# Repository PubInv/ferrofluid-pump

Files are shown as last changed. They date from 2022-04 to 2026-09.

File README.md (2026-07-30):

# Ferrofluid Pump
## July 7th

Using Rob's pump with three electromagnets and one permanent magnet at priming, with a 10 amp power supply,
with a period of 300 ms and {0.0,0.4} interval timing, we measured 8 grams per minute, the best that we have yet.

## Previously

Ferrofluid pump with rotating water blobs and no moving parts

A video of best results:

[https://youtu.be/B2Wuy3dDc4E?si=2YtM-PyZvu_GHdCr](https://youtu.be/B2Wuy3dDc4E?si=2YtM-PyZvu_GHdCr)

# The Latest Version

Our latest multi-magnet version (which has not yet been tested) is here:





# The Boat-Pump Idea

This idea seems to work:

<a href="https://youtube.com/shorts/PQ8AnhncvDY?feature=share" title="Boat Pump Example">
  magnet switched on and off asking as pump
</a>

[https://youtube.com/shorts/PQ8AnhncvDY?feature=share](https://youtube.com/shorts/PQ8AnhncvDY?feature=share)

As a prelude to the 7-circle pump described in the technical paper you can find in the "doc" directory here,
we are attempting to make a very, very simple, pump.
The images below represent our simple "pump" idea. 
We just raise a small bolus of fluid, and then drop it onto a ramp.
This performance of this pump is being worked out, but of course 
it is weak.
The "head" is just a few millimeters, and the flow has not yet been measured.
However, we think it is still important in that it is indeed a
pump with no moving parts.



We use a hot-melt glue to try to seal the "chamber" so that the fluid will flow down the ramp:



# Possible Reading

[https://www.researchgate.net/publication/245883107_Design_fabrication_and_testing_of_fixed-valve_micro-pumps](https://www.researchgate.net/publication/245883107_Design_fabrication_and_testing_of_fixed-valve_micro-pumps)

A closely related paper is:
article{ando2009ferrofluidic,
  title={Ferrofluidic pumps: a valuable implementation without moving parts},
  author={Ando, Bruno and Ascia, Alberto and Baglio, Salvatore and Pitrone, Nicola},
  journal={IEEE Transactions on Instrumentation and Measurement},
  volume={58},
  number={9},
  pages={3232--3237},
  year={2009},
  publisher={IEEE}
}

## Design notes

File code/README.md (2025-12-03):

# microPython on ESP32

* Install UART driver [1]
* Install Thonny IDE [2], [3]
* Download microPython firmware [4]
* Clone esptool [5]
* Install micropython to the ESP32
  * Either directly using esptool
  * Or using Thonny Tools -> Options -> Interpreter -> Install microPython
* Select the ESP32 as the runtime to use and auto-select port

[1] - https://www.silabs.com/developers/usb-to-uart-bridge-vcp-drivers?tab=downloads

[2] - https://randomnerdtutorials.com/getting-started-thonny-micropython-python-ide-esp32-esp8266/

[3] - https://thonny.org/

[4] - https://micropython.org/resources/firmware/ESP32_GENERIC-20240222-v1.22.2.bin

[5] - https://github.com/espressif/esptool

# Run pump.py on the ESP32

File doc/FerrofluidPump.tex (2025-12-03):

\documentclass[12pt]{article}
%Uncomment next line if AMS fonts required
%\usepackage{iopams}
\usepackage{graphicx}
\usepackage{hyperref}   % to set up hyperlinks
\hypersetup{
	colorlinks=true,
	linkcolor=blue,
	citecolor=blue,
	urlcolor=blue,
}

\begin{document}

%%\note{A novel passive
%%ferrofluid check (one-way) valve}

\title{Pumping Ferrofluid With Only Liquid}

\maketitle

%%% first author
\author{Robert L. Read}

\begin{abstract}

  Currently this is very preliminary. This is an attempt to design a pump that can efficiently pump ferrofluid with no moving parts
  except the ferrofluid and two blobs of an immiscible, incompressible fluid, such as water.
  Eliminating moving parts allows miniaturization and potentially fabrication as a chip.
  A miniature pump could be used for cooling a chip and for ``lab on a chip'' applications.
  The proposed design uses two permanent magnets and seven controllable electromagnets.
  The design was developed from considering the minimal topological connection of fixed chambers.
  It has four distinct phases, each phase having a distinct magnetic configuration.
\end{abstract}

%
% Uncomment for keywords
\vspace{2pc}
\noindent{\it Keywords}: ferrofluid pump

% Uncomment if a separate title page is required
%\maketitle
%
% For two-column output uncomment the next line and choose [10pt] rather than [12pt] in the \documentclass declaration
%\ioptwocol
%

%%%%%%%%%%%%%%%%%%%%%%%%%%%%%%%%%%%%%%%%%%%%%%%%%%%%%%%%%%%%%%%%%%%%%%
\section{Introduction}

Ferrofluid can be manipulated by electronically controlled magnetic
fields to exert force on fluids\cite{torres2014recent,kole2021engineering,ozbey2015modeling}.
This makes it possible to build pneumatic or hydraulic
devices, perhaps on very small scales,
such as a single chip\cite{yamahata2003ferrofluid,hatch2001ferrofluidic}, to
miniaturize fluid handling.
This has been proposed for biomedical purposes\cite{michelson2019novel}
that would use water or body fluids,
although this paper reports only on experiments done with air.
Miniature pumps and valves could be used to make a “lab on a chip” (LOC) or
even to heat or cool different chip areas.

%%%%%%%%%%%%%%%%%%%%%%%%%%%%%%%%%%%%%%%%%%%%%%%%%%%%%%%%%%%%%%%%%%%%%%
\section{Related Research}

A number of papers report on ferrofluid pumps, focusing in particular
on micropump and lab-on-a-chip applications\cite{ozbey2015modeling,hsu2018biocompatible}.
Many of these papers use
a version of mechanical valve not based on passive
ferrofluid, even though they move a ferrofluid bolus
with a magnetic field.
For example,
a corrugated silicone micro valve\cite{yamahata2003ferrofluid,yamahata2005plastic}
has been reported.
Other researchers use active valves, which require synchronization with
the ferrofluid plug to form a pump,
such as \cite{menz2000fluidic}, which
describes an active {\em T-Valve} with a moving ferrofluid plug, and
\cite{ando2009ferrofluidic} describes a complete fluid pump with valves
that use
active control of a ferrofluid bolus.
At least two additional kinds of active valves, a {\em well valve} and
{\em Y-valve}, have
been described\cite{hartshorne2004ferrofluid}.
Active control is possible because the
action of the plunger or bolus may be synchronized with the opening and closing
of the valves.
Nonetheless a passive valve would be simpler and less
expensive, and would not require knowledge of the timing of the
plunger.

An interesting functional micropump in which the
moving ferrofluid bolus merges with a fixed ferrofluid valve and then
separates on each pumping cycle has been described\cite{hatch2001ferrofluidic}.

An interesting devices induces a flow directly in ferrofluid
with no moving parts,
presumable based on the rotation of clumps of ferrofluid
\cite{mao2011direct}.

A good motivation of the need to make a ferrofluid pump and a functioning pump
is presented by \cite{YAO2024115537}. The goal of this work is to something similar
to Yao with no moving parts.

\section{The Idea}

There is no known way to directly move a mass of ferrfluid which is immersed in
ferrofluid.
The idea of moving a ferrofluid plug or bolus which is bouneded by air or water
via electromagnets turned on or off is well known. A slight inversion of this
idea is to use two boluses to trap a blob of water. The water thus remains
a separator. In the diagrams below it is represented as a ``W'',
and the ferrofluid as an ``F''.
The separator allows us to move the bolus slightly.
In order to create a pump, we need to recycle this separator, rather than
moving it once, as in a piston.

If we combine this with the idea of a moving bolus ``picking up'' some ferrofluid
and then dropping some of that ferrofluid, we can have a two circulating water blobs
and two circulating ferrofluid plugs. One ferrofluid plug, which is moving from the
inlet to the outlet, is larger.
The other plug is smaller, and merely separating the water plugs as it is returned.

If we reduce this to a minimal configuration, we have a circle of seven regions
of equal size. The inlet and the outlet prevent the water blobs from escaping by
having permanent magnets in place. The water blobs can never displace these
locks, represented by ``L'' in our diaggram. The inlet of the pump has an
inexhaustible supply of ferrofluid represented as a source (``S''). The
outlet is represented as a drain ``D''.

The water plugs must always be kept separated by ferrofluid plugs. However,
these plugs can pull fluid from the source and push it into the drain if
so driven by the changing magnets in the seven dynamic regions.
By cycling through four configurations as depicted, we can move ferrofluid
from the source to the drain.

\begin{figure}
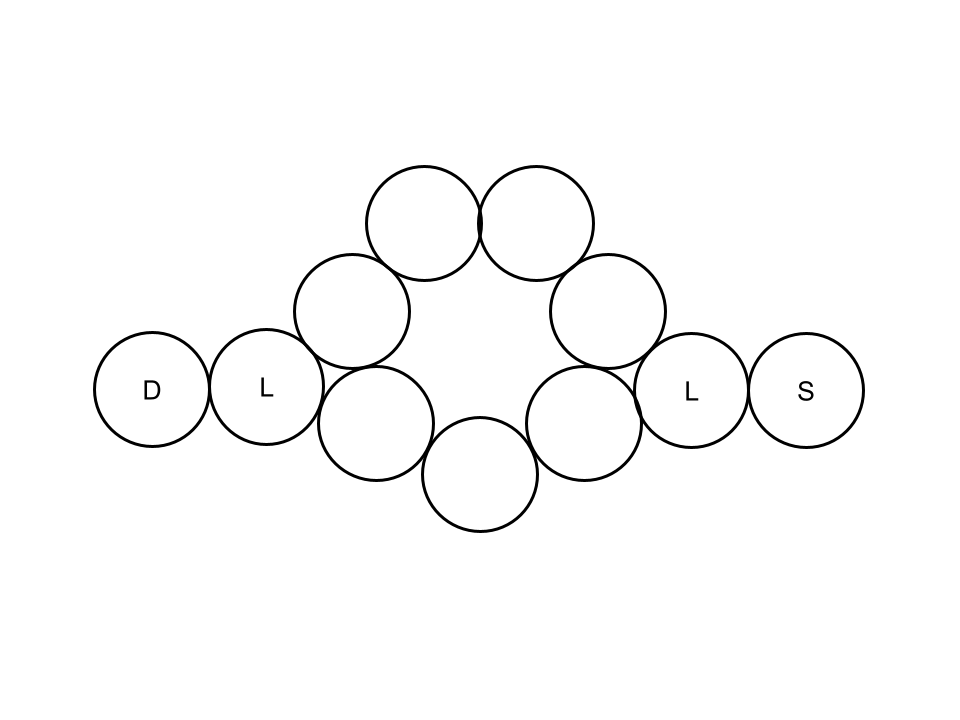
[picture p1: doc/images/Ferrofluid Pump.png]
\centerline{}
\caption{The Pump Schematic}
\label{fig_pumpschematic}
\end{figure}

\begin{figure}
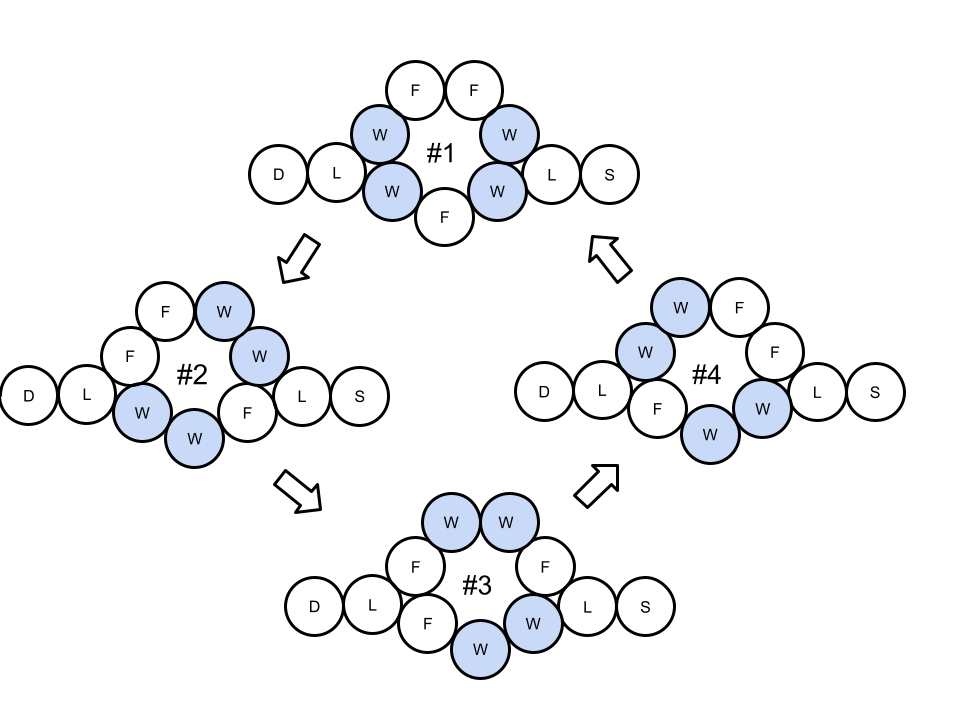
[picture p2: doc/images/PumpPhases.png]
\centerline{}
\caption{The Pump Schematic}
\label{fig_pumpschematic}
\end{figure}

\section{A Simple Test Apparatus}

It is easy to source permanent magnets and difficult to source electomagnets with
the precise shapes neede for this project.
A test apparatus using only permanent magnets moved by hand to match the 4-stroke cylce
of the pump should allow us to test the hypothesis that this pump will work and measure
flow on a per-cycle basis.
This approach will postpone the need to develop the electromanets.

We therefore propose to make 3D printed apparatus that has cages for permanent magnets
which can be moved into the pump ring and out of the pump ring to simulated turning
an elctromagnet on and off.
These cages are necessary because strong permanent magnets tend to want to fly into
each other and must be carefully constrained.
We believe we can furthermore make handles which we can glue to the magnets with
hot-melt glue to make the motion of the magnets easier to effect.
We suspect that the magnest will stay in place when in the ring,
and have to held when out of the ring, which may require three hands or
some dextrous holding.

\section{A Separate Test}

The idea presented in the paper assumes that a bolus of water which is trapped
between two boluses of ferrofluid will remain coherent. That is, it will
resist the intrusion of ``fingers'' or ferrofluid into the bolus of water.
For exmample, if a thin finger of ferrofluid reached into the water and
reached the other side, the ferrofluid could flow through the water by means
of this channel, and the moving boluses of water might not force the
ferrofluid to move in the way that would make this invention functional.

We can test this with a simpler apparatus.
Let us take a clear tube of acrylic and two strong permanent magnets.
Adhere the two magnets with the same polarity rather close to each other,
say 2 inches apart.
Close one end of the tube and mount it vertically.
Fill the tube with ferrofluid to just above the lower magnet.
Then fill the tube with water to just below the higher magnet.
Then fill the rest of the tube with ferrofluid.

My hypothesis is that the water will remain a coherent mass without
instrusions of ferrofluid. If we open the ends of the tube, we will
be able to slide out two magnets in relation to the tube, moving the
bolus with it.

I believe the reason the intrusions do not occur is what
Joe Herschberge has named ``magnetic buoyancy''. An intrusion
would increase potential energy, not because of the ferrofluid
in between the two magnets, but because it for a displacement of
water into the ferrofluid which is in a strong field.
That displacement would increase the potential energcy, and
therefore a force which we name {\em magnetic buoyancy} opposes it.

\subsection{A Way To Test it Simply}

Lawrence Kincheloe has provided this observation about testing this easily:

The 2d Ferro fluid pump could be easily executed with sheets of acrylic to form a fluid chamber. An external turntable with magnets attached could be used to test the idea, as displayed in the infographic.

\section{Motivation}

Lawrence Kincheloe suggested this approach:

Ferro fluids could be used for vein massages and pumping by direct injection into the veins. This is predicated on a biocompatible ferro fluid where the lipid shell and nano scale ferride can be adsorbed by the body and act like an iron supplement. The direction of an external magnetic field will direct the ferro fluid to a particular location and could allow for mechanical agitation, and a pumping action using a rhythmic compression and expansion of plasma displacement within the veins.

\section{Conclusions}

\section{TODO}

Study this: \url{http://citeseerx.ist.psu.edu/viewdoc/download?doi=10.1.1.719.4343&rep=rep1&type=pdf}

\section{Acknowledgements}

This paper was an outgrowth the the Passive Ferrrofluid Check Valve (PFCV) \cite{stuckeynovel}
reported by Veronica Stuckey and Robert L. Read. Veronica Stuckery 3D printed
some of the apparatus.

\section*{References}

This paper gives a theoretic description of flow induced by magnetic gradient:

https://pubs.aip.org/aip/pof/article/37/1/017102/3329059/Gradient-magnetic-field-driven-ferrofluid-pipe

\bibliographystyle{unsrt}
% Here's where you specify the bibliography database file.
% The full file name of the bibliography database for this
% article is asme2e.bib. The name for your database is up
% to you.
\bibliography{ffcv}

\end{document}

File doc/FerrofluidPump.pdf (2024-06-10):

# Pumping Ferrofluid With Only Liquid

### June 9, 2024

Robert L. Read

Abstract

Currently this is very preliminary. This is an attempt to design a pump that can efficiently pump ferrofluid with no moving parts except the ferrofluid and two blobs of an immiscible, incompressible fluid, such as water. Eliminating moving parts allows miniaturization and potentially fabrication as a chip. A miniature pump could be used for cooling a chip and for “lab on a chip” applications. The proposed design uses two permanent magnets and seven controllable electromagnets. The design was developed from considering the minimal topological connection of fixed chambers. It has four distinct phases, each phase having a distinct magnetic configuration.

Keywords: ferrofluid pump

## 1 Introduction

Ferrofluid can be manipulated by electronically controlled magnetic fields to exert force on fluids[1, 2, 3]. This makes it possible to build pneumatic or hydraulic devices, perhaps on very small scales, such as a single chip[4, 5], to miniaturize fluid handling. This has been proposed for biomedical purposes[6] that would use water or body fluids, although this paper reports only on experiments done with air. Miniature pumps and valves could be used to make a “lab on a chip” (LOC) or even to heat or cool different chip areas.

1

## 2 Related Research

A number of papers report on ferrofluid pumps, focusing in particular on micropump and lab-on-a-chip applications[3, 7]. Many of these papers use a version of mechanical valve not based on passive ferrofluid, even though they move a ferrofluid bolus with a magnetic field. For example, a corrugated silicone micro valve[4, 8] has been reported. Other researchers use active valves, which require synchronization with the ferrofluid plug to form a pump, such as [9], which describes an active T-Valve with a moving ferrofluid plug, and [10] describes a complete fluid pump with valves that use active control of a ferrofluid bolus. At least two additional kinds of active valves, a well valve and Y-valve, have been described[11]. Active control is possible because the action of the plunger or bolus may be synchronized with the opening and closing of the valves. Nonetheless a passive valve would be simpler and less expensive, and would not require knowledge of the timing of the plunger. An interesting functional micropump in which the moving ferrofluid bolus merges with a fixed ferrofluid valve and then separates on each pumping cycle has been described[5].
An interesting devices induces a flow directly in ferrofluid with no moving parts, presumable based on the rotation of clumps of ferrofluid [12].
A good motivation of the need to make a ferrofluid pump and a functioning pump is presented by [?]. The goal of this work is to something similar to Yao with no moving parts.

## 3 The Idea

There is no known way to directly move a mass of ferrfluid which is immersed in ferrofluid. The idea of moving a ferrofluid plug or bolus which is bouneded by air or water via electromagnets turned on or off is well known. A slight inversion of this idea is to use two boluses to trap a blob of water. The water thus remains a separator. In the diagrams below it is represented as a “W”, and the ferrofluid as an “F”. The separator allows us to move the bolus slightly. In order to create a pump, we need to recycle this separator, rather than moving it once, as in a piston.
If we combine this with the idea of a moving bolus “picking up” some ferrofluid and then dropping some of that ferrofluid, we can have a two circulating water blobs and two circulating ferrofluid plugs. One ferrofluid

2

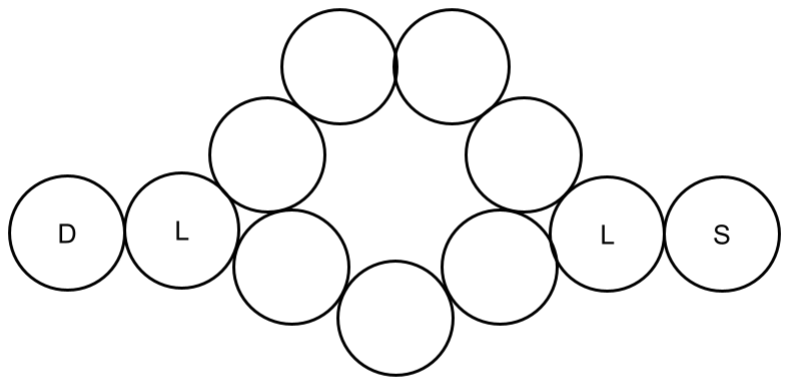
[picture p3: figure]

Figure 1: The Pump Schematic

plug, which is moving from the inlet to the outlet, is larger. The other plug is smaller, and merely separating the water plugs as it is returned.
If we reduce this to a minimal configuration, we have a circle of seven regions of equal size. The inlet and the outlet prevent the water blobs from escaping by having permanent magnets in place. The water blobs can never displace these locks, represented by “L” in our diaggram. The inlet of the pump has an inexhaustible supply of ferrofluid represented as a source (“S”). The outlet is represented as a drain “D”.
The water plugs must always be kept separated by ferrofluid plugs. However, these plugs can pull fluid from the source and push it into the drain if so driven by the changing magnets in the seven dynamic regions. By cycling through four configurations as depicted, we can move ferrofluid from the source to the drain.

3

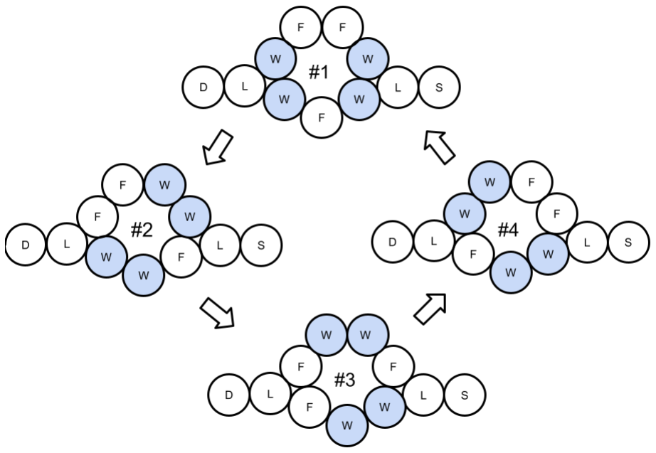
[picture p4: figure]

Figure 2: The Pump Schematic

4

## 4 A Simple Test Apparatus

It is easy to source permanent magnets and difficult to source electomagnets with the precise shapes neede for this project. A test apparatus using only permanent magnets moved by hand to match the 4-stroke cylce of the pump should allow us to test the hypothesis that this pump will work and measure flow on a per-cycle basis. This approach will postpone the need to develop the electromanets.
We therefore propose to make 3D printed apparatus that has cages for permanent magnets which can be moved into the pump ring and out of the pump ring to simulated turning an elctromagnet on and off. These cages are necessary because strong permanent magnets tend to want to fly into each other and must be carefully constrained. We believe we can furthermore make handles which we can glue to the magnets with hot-melt glue to make the motion of the magnets easier to effect. We suspect that the magnest will stay in place when in the ring, and have to held when out of the ring, which may require three hands or some dextrous holding.

## 5 A Separate Test

The idea presented in the paper assumes that a bolus of water which is trapped between two boluses of ferrofluid will remain coherent. That is, it will resist the intrusion of “fingers” or ferrofluid into the bolus of water. For exmample, if a thin finger of ferrofluid reached into the water and reached the other side, the ferrofluid could flow through the water by means of this channel, and the moving boluses of water might not force the ferrofluid to move in the way that would make this invention functional.
We can test this with a simpler apparatus. Let us take a clear tube of acrylic and two strong permanent magnets. Adhere the two magnets with the same polarity rather close to each other, say 2 inches apart. Close one end of the tube and mount it vertically. Fill the tube with ferrofluid to just above the lower magnet. Then fill the tube with water to just below the higher magnet. Then fill the rest of the tube with ferrofluid.
My hypothesis is that the water will remain a coherent mass without instrusions of ferrofluid. If we open the ends of the tube, we will be able to slide out two magnets in relation to the tube, moving the bolus with it.
I believe the reason the intrusions do not occur is what Joe Herschberge

5

has named “magnetic buoyancy”. An intrusion would increase potential energy, not because of the ferrofluid in between the two magnets, but because it for a displacement of water into the ferrofluid which is in a strong field. That displacement would increase the potential energcy, and therefore a force which we name magnetic buoyancy opposes it.

### 5.1 A Way To Test it Simply

Lawrence Kincheloe has provided this observation about testing this easily: The 2d Ferro fluid pump could be easily executed with sheets of acrylic to form a fluid chamber. An external turntable with magnets attached could be used to test the idea, as displayed in the infographic.

## 6 Motivation

Lawrence Kincheloe suggested this approach:
Ferro fluids could be used for vein massages and pumping by direct injection into the veins. This is predicated on a biocompatible ferro fluid where the lipid shell and nano scale ferride can be adsorbed by the body and act like an iron supplement. The direction of an external magnetic field will direct the ferro fluid to a particular location and could allow for mechanical agitation, and a pumping action using a rhythmic compression and expansion of plasma displacement within the veins.

## 7 Conclusions

## 8 TODO

Study this: http://citeseerx.ist.psu.edu/viewdoc/download?doi=10.1.1.719.4343&rep=rep1&type=pdf (http://citeseerx.ist.psu.edu/viewdoc/download?doi=10.1.1.719.4343&rep=rep1&type=pdf)

## 9 Acknowledgements

This paper was an outgrowth the the Passive Ferrrofluid Check Valve (PFCV)
[13] reported by Veronica Stuckey and Robert L. Read. Veronica Stuckery 3D printed some of the apparatus.

6

## References

## References

[1] I Torres-D´ıaz and C Rinaldi. Recent progress in ferrofluids research: novel applications of magnetically controllable and tunable fluids. Soft matter, 10(43):8584–8602, 2014.
[2] Madhusree Kole and Sameer Khandekar. Engineering applications of ferrofluids: A review. Journal of Magnetism and Magnetic Materials, page 168222, 2021.
[3] Arzu Ozbey, Mehrdad Karimzadehkhouei, Sinan Eren Yal¸cın, Devrim ¨ Gozuacik, and Ali Ko¸sar. Modeling of ferrofluid magnetic actuation with dynamic magnetic fields in small channels. Microfluidics and Nanofluidics, 18(3):447–460, 2015.
[4] Christophe Yamahata, Mathieu Chastellain, Heinrich Hofmann, and Martin AM Gijs. A ferrofluid micropump for lab-on-a-chip applications. In Techn. Digest Eurosensors XVII, The 17th Europ. Conf. On Solid State Transducers, number CONF, 2003.
[5] Anson Hatch, Andrew Evan Kamholz, Gary Holman, Paul Yager, and Karl F Bohringer. A ferrofluidic magnetic micropump. Journal of Microelectromechanical systems, 10(2):215–221, 2001.
[6] Trevor Michelson, Joshua Rudnick, Joshua Baxter, and Reza Rashidi. A novel ferrofluid-based valve-less pump. In ASME International Mechanical Engineering Congress and Exposition, volume 59445, page V007T08A009. American Society of Mechanical Engineers, 2019.
[7] Meng-Chun Hsu, Ahmed Alfadhel, Farzad Forouzandeh, and David A Borkholder. Biocompatible magnetic nanocomposite microcapsules as microfluidic one-way diffusion blocking valves with ultra-low opening pressure. Materials & design, 150:86–93, 2018.
[8] Christophe Yamahata, Mathieu Chastellain, Virendra K Parashar, Alke Petri, Heinrich Hofmann, and Martin AM Gijs. Plastic micropump with ferrofluidic actuation. Journal of microelectromechanical systems, 14(1):96–102, 2005.

7

[9] A Menz, W Benecke, R Perez-Castillejos, JA Plasza, J Esteve, N Garcia, J Higuero, and T Diez-Caballero. Fluidic components based on ferrofluids. In 1st Annual International IEEE-EMBS Special Topic Conference on Microtechnologies in Medicine and Biology. Proceedings (Cat. No. 00EX451), pages 302–306. IEEE, 2000.
[10] Bruno Ando, Alberto Ascia, Salvatore Baglio, and Nicola Pitrone. Ferrofluidic pumps: a valuable implementation without moving parts. IEEE Transactions on Instrumentation and Measurement, 58(9):3232–3237, 2009.
[11] Herb Hartshorne, Christopher J Backhouse, and William E Lee. Ferrofluid-based microchip pump and valve. Sensors and Actuators B: Chemical, 99(2-3):592–600, 2004.
[12] Leidong Mao, Shihab Elborai, Xiaowei He, Markus Zahn, and Hur Koser. Direct observation of closed-loop ferrohydrodynamic pumping under traveling magnetic fields. Physical review B, 84(10):104431, 2011.
[13] Jie Yao, Hui Li, Jun Yu, Decai Li, Tingxin Liu, and Zhenkun Li. Research on the backpressure and backflow of a ferrofluid linear pump. Sensors and Actuators A: Physical, 375:115537, 2024.
[14] Veronica Stuckey and Robert Read. A novel passive ferrofluid one-way (check) valve.

8

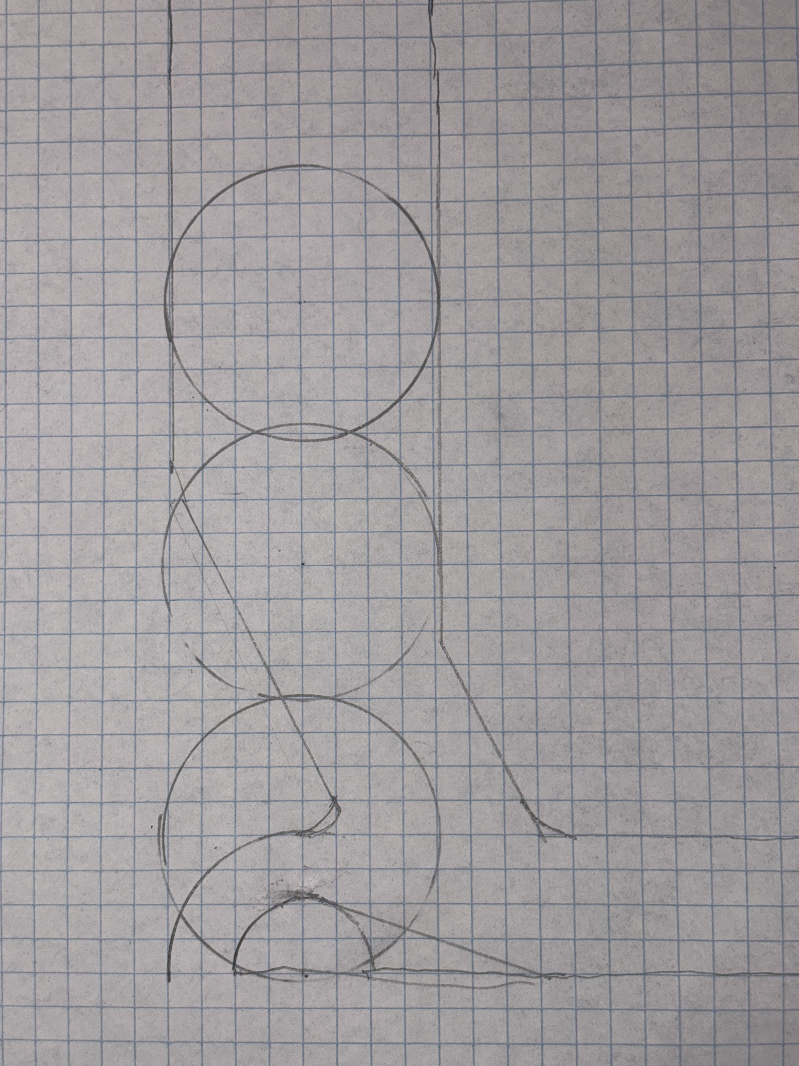
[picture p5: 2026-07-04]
Jul3RedesignofDiodicRamp.JPG

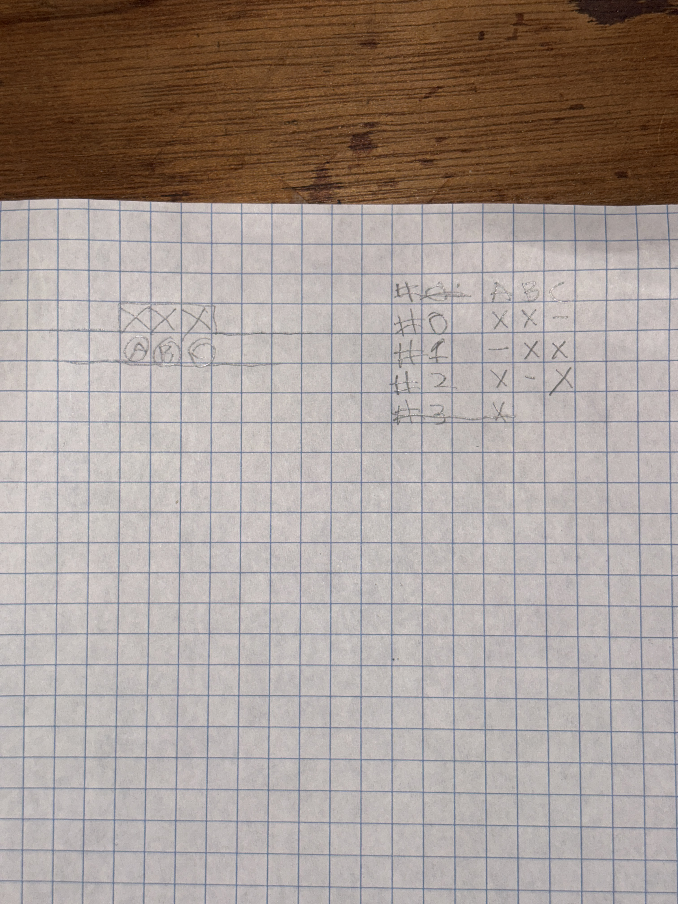
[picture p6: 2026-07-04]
Jule3IdeaForSimpleWaterPump.JPG

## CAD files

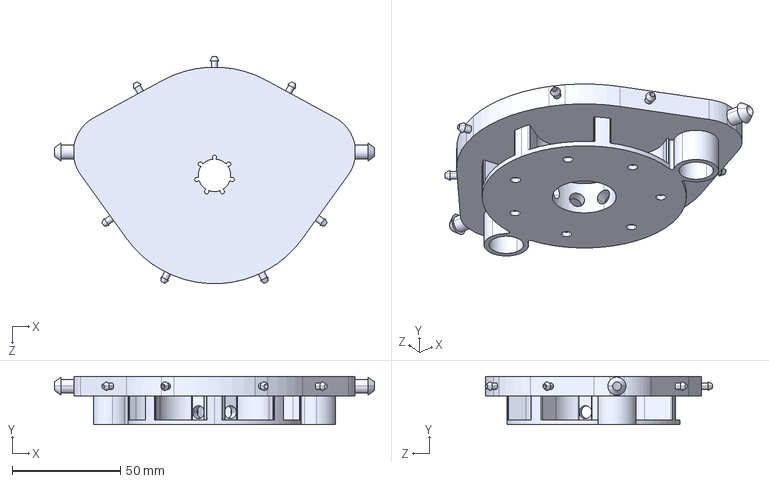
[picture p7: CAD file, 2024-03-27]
models/Electromagnet7Circle/Pump.STEP
147.8 x 22.2 x 104.8 mm

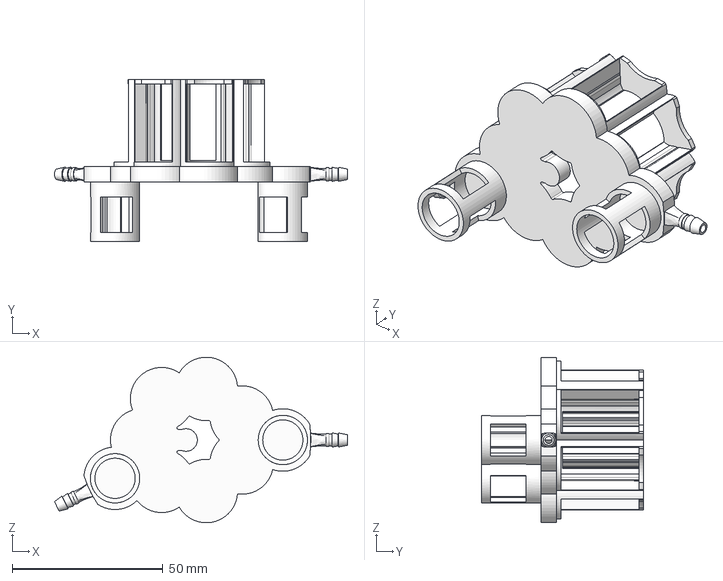
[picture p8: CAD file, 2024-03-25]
models/ferofluid pump V1/ferofluid pump V1.step
97.0 x 53.7 x 54.8 mm

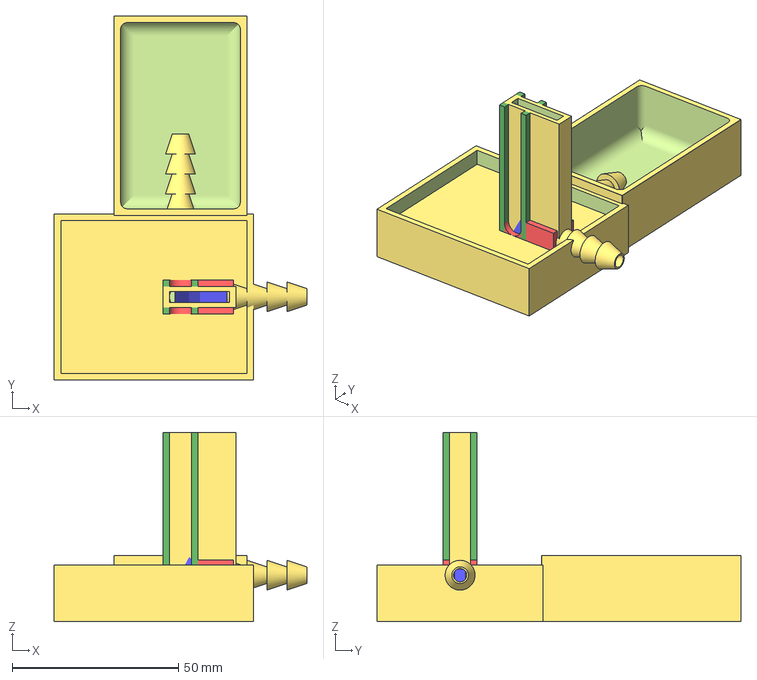
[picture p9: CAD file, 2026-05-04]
models/PumpWithTray.3mf
76.0 x 109.5 x 57.0 mm

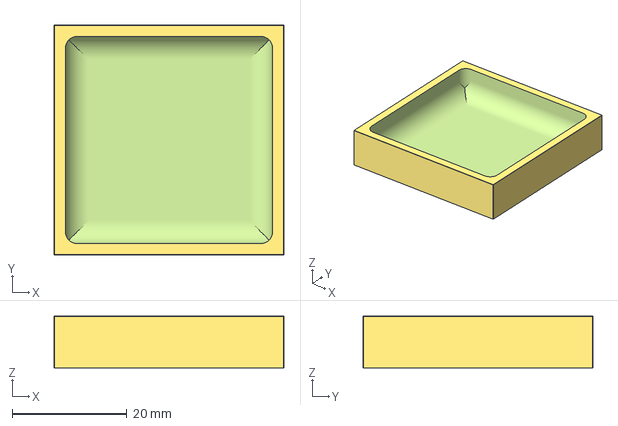
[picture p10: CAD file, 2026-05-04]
models/Tray.3mf
40.0 x 40.0 x 9.00 mm

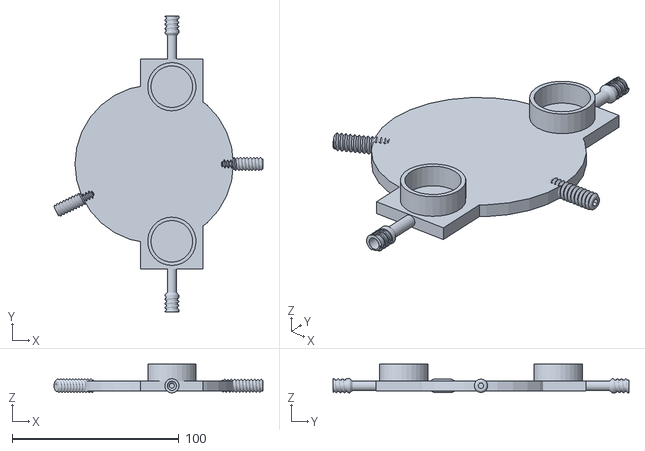
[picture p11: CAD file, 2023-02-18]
models/WaterBlobPump.stl
125.5 x 177.6 x 17.2

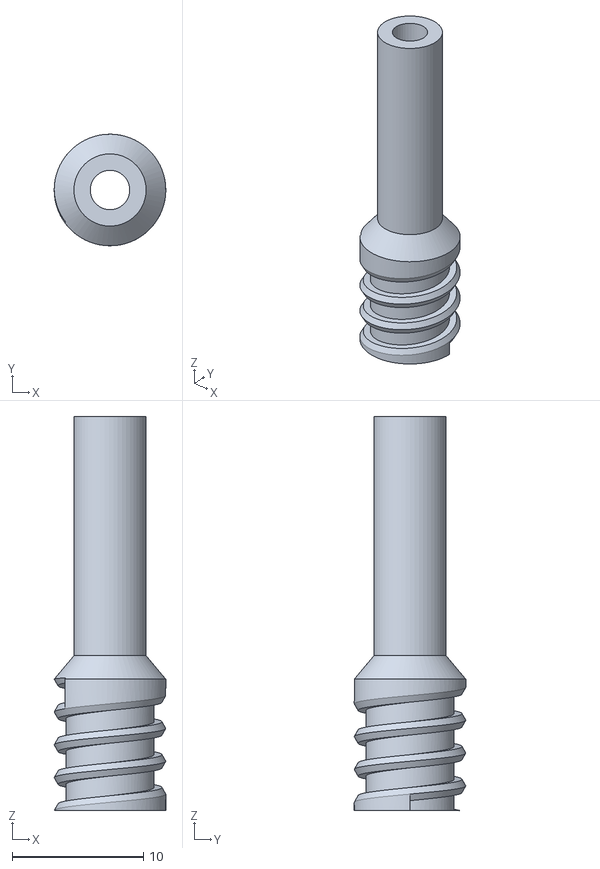
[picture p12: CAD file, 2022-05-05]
models/Body1.stl
8.50 x 8.50 x 30.0

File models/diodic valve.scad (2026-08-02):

chimney_width = 20;
chimney_height = 40;
wall = 2;
tube_width = 10;
tube_length = 2*chimney_width;
extrude_h = 15;

magnet_diameter = 6.25+0.25;
magnet_radius = magnet_diameter/2; // radius of magnet cylinders
// remove this in when integrating code in make pump file
qm_mm = magnet_radius / 2;

chimney_height_qms = 15;

$fn = 100;

// An attempt to make a "faucet shape".
module faucet_hook() {
   
   b_mm = (3/4)*qm_mm; // this is a basic quantity we use for this shape
   pylon_width_mm = (1/2)*b_mm;
   channel_width_mm = (4/4)*b_mm;
   hook_width_mm = (1/2)*b_mm;
   
   inner_hook_height_mm = hook_width_mm + channel_width_mm;
    
    // this is the main inlet valve, from which 
    // which we intersect with the +y, -x quadrant
    // to make it easier to use
    intersection() {
        translate([0,100])
        square([200,200],center = true);
        union() {
            difference() {
                inlet_curve_outer_radius = hook_width_mm + channel_width_mm + pylon_width_mm;
                circle(inlet_curve_outer_radius);
            
                difference() {
                    inlet_curve_inner_radius = channel_width_mm + pylon_width_mm;
                    circle(inlet_curve_inner_radius);
                        
                    inlet_curve_core_radius = pylon_width_mm;
                    circle(inlet_curve_core_radius);
                }
            }
        }
    }
    
    
    // now add a rounding curve at the edge to 
    // 
    translate([pylon_width_mm * 3/2 +channel_width_mm,0])
    circle(pylon_width_mm/2);
    
    polygon(points = [
        [b_mm*1.35,inner_hook_height_mm],
        [-b_mm*2,b_mm*5],
        [-b_mm*2,inner_hook_height_mm]
    ]);
    polygon(points = [
        [-b_mm*2,inner_hook_height_mm],
        [-b_mm*1.0,inner_hook_height_mm],
        [-b_mm*2,0]
    ]);
    // create the pylon
    translate([0,-(b_mm*50/2)])
    square([pylon_width_mm*2,b_mm*50],center=true);
}


module chimney_back_wall() {
    // Start at the most critical, the edge of the fluid
    theta = 30;
    dx = qm_mm*cos(theta);
    dy = qm_mm*sin(theta);
    polygon(points = [
        [-qm_mm*2,qm_mm*2.25+dy],
        [-qm_mm*2,qm_mm*(chimney_height_qms-2)],
        [-qm_mm*2,qm_mm*2]
    ]
    );
}

module chimney_front_wall() {
    translate([qm_mm*3,qm_mm*2.5])
    circle(qm_mm);
    start = [qm_mm*2,qm_mm*2.5];
    polygon(points = [
        start,
        [qm_mm*2,qm_mm*(chimney_height_qms+1.5)],
        [qm_mm*4,qm_mm*(chimney_height_qms+1.5)],
        [qm_mm*4,qm_mm],
        [qm_mm*2.7,qm_mm*1.55],
        start
        ]
    );
    translate([-(qm_mm/2+qm_mm*2),(qm_mm*chimney_height_qms+qm_mm*3)/2])
    square([qm_mm,qm_mm*chimney_height_qms],center=true);
}

module inlet_curve() {
   inlet_curve_center_x_mm = 0;
   inlet_curve_center_y_mm = 0;
    
    // this is the main inlet valve, from which 
    // which we intersect with the +y, -x quadrant
    // to make it easier to use
    intersection() {
        translate([-100,100])
        square([200,200],center = true);
        union() {
            difference() {
                inlet_curve_outer_radius = 3.5*qm_mm;
                circle(inlet_curve_outer_radius);
            
                difference() {
                    inlet_curve_inner_radius = 2.5*qm_mm;
                    circle(inlet_curve_inner_radius);
                        
                    inlet_curve_core_radius = 1.5*qm_mm;
                    circle(inlet_curve_core_radius);
                }
            }
        }
    }
    // now add a rounding curve at the edge to 
    // 
    translate([0,qm_mm*2.85])
    circle(qm_mm/3);
}
module outlet_ramp() {
    polygon([[0,0],
    [0,qm_mm*1.5],
    [qm_mm*4,0]
    ]);
}
// Note: We have to understand the coordinate 
// system of the pump. The x=0 coordinate is
// centered on the center of the magnets.
// The y coordinate is the bottom of the lowest
// magnet.
// Note: this is being produced in "positive form",
// with material NOT present where the ferrofluid will be.
module diodic_valve(){
// Chimney
//    difference(){
//        chimney_hollow(chimney_width, chimney_height    , wall);
//        inside();
//    }
    
// // outlet portion
//    difference(){
//        tube_hollow();
//        inside();
//    }
    
//    translate([0, wall, 0])
//        circle(2, $fn=25);
    
//    translate([0, -tube_width+2*wall])
//        circle(4, $fn=25);
    translate([-qm_mm,qm_mm*10])
    faucet_hook();

    chimney_back_wall();
    chimney_front_wall();
    
    outlet_ramp();
 
}

// linear_extrude(height = extrude_h)
//    all();

diodic_valve();

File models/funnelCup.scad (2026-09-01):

funnelWidth = 2; //2 or 3 times 6.35 mm, or 1/2 inch
funnelHeight = 0.5;
funnelThickness=0.05;
extrudeHeight = 2;

module shearX_Z(s) {
    multmatrix([
        [1, 0, s, 0],
        [0, 1, 0, 0],
        [0, 0, 1, 0]
    ])
    children();
}

module funnelCupFrame(w,h,t,e){
    translate([0,0,e/2])
    linear_extrude(height = e,convexity = 3, scale=4,center=true)
    difference() {
        square([w,w],center=true);
        offset(delta = -t) square([w,w],center=true);
    }
}

module funnelOutlet (w,t){
    translate([-w/2,0,0])
    rotate([-90,0,0])
    translate([0,0,-w/2])
    rotate_extrude(angle=90, convexity=10,$fn=100) 
    difference() {
        square([w,w]);
        offset(delta = -t) square([w,w]);
    }
    
}

module outletPipe(w,t,e){
    translate([-w/2,0,-w/2])
    rotate([0,-90,0]) 
    linear_extrude(height = e, scale = 0.5)
    difference() {
        square([w,w],center=true);
        offset(delta = -t) square([w,w],center=true);
    }
}


module funnel() {

shearX_Z(1.5)
funnelCupFrame(w=funnelWidth,h=funnelHeight,t=funnelThickness, e= extrudeHeight);

funnelOutlet(w=funnelWidth, t=funnelThickness);

outletPipe(w=funnelWidth, t=funnelThickness, e= extrudeHeight);

}

funnel();

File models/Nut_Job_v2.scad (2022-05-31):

/* 'Nut Job' nut, bolt, washer and threaded rod factory by Mike Thompson 1/12/2013, Thingiverse: mike_linus
 *
 * Modified by Robert L. Read, 2022, to make it includable. 
 * Licensing: This work is licensed under a Creative Commons Attribution-NonCommercial-ShareAlike 3.0 Australia License.
 * Further information is available here - http://creativecommons.org/licenses/by-nc-sa/3.0/au/deed.en_GB
 *
 * v2 8/12/2013 - added socket head types
 * v3 2/11/2014 - adjusted wing nut algorithm for better behaviour with unusual nut sizes and added ISO262 metric references
 * v4 31/12/2014 - added optional texture to socket heads, added ability to change the number of facets for a hex head
 * and adjusted wingnut base level on certain nut sizes
 * v5 11/1/2015 - added phillips and slot drive types and improved texture handling 
 * v6 21/2/2015 - added wing ratio to wingnuts 
 * v7 6/3/2016 - added extended options to control number of facets on nuts, square sockets (or any number of facets) and socket depth control
 * v8 1/1/2017 - modified library code to remove dependence on deprecated 'assign' statement
 * 
 * This script generates nuts, bolts, washers and threaded rod using the library 
 * script: polyScrewThead.scad (modified/updated version polyScrewThread_r1.scad)
 * http://www.thingiverse.com/thing:8796, CC Public Domain
 *
 * Defaults are for a 8mm diameter bolts, rod, matching nuts and wing nuts that work well together
 * without cleanup or modification. Some default parameters such as the nut outer diameter are deliberately
 * altered to produce a snug fit that can still be hand tightened. This may need to be altered
 * depending on individual printer variances, slicing tools, filament etc. Suggest printing a matching
 * bolt and nut and adjusting as necessary.  Note: slow print speeds, low temperatures and solid
 * fill are recommended for best results.
 */

/* [Component Type] */

type						    = "bolt";//[nut,bolt,rod,washer]

/* [Bolt and Rod Options] */

//Head type - Hex, Socket Cap, Button Socket Cap or Countersunk Socket Cap (ignored for Rod)
head_type              			= "hex";//[hex,socket,button,countersunk]
//Drive type - Socket, Phillips, Slot (ignored for Hex head type and Rod)
drive_type              		= "socket";//[socket,phillips,slot]
//Distance between flats for the hex head or diameter for socket or button head (ignored for Rod)
head_diameter    				= 12;	
//Height of the head (ignored for Rod)
head_height  					= 5;	
//Diameter of drive type (ignored for Hex head and Rod)
drive_diameter					= 5;	
//Width of slot aperture for phillips or slot drive types
slot_width					    = 1;
//Depth of slot aperture for slot drive type
slot_depth 					    = 2;
//Surface texture (socket head only)
texture                         = "exclude";//[include,exclude]
//Outer diameter of the thread
thread_outer_diameter           = 8;		
//Thread step or Pitch (2mm works well for most applications ref. ISO262: M3=0.5,M4=0.7,M5=0.8,M6=1,M8=1.25,M10=1.5)
thread_step    					= 2;
//Step shape degrees (45 degrees is optimised for most printers ref. ISO262: 30 degrees)
step_shape_degrees 				= 45;	
//Length of the threaded section
thread_length  					= 25;	
// Local Mod
//thread_length = 12;
//Countersink in both ends
countersink  					= 2;	
//Length of the non-threaded section
non_thread_length				= 0;	
//Diameter for the non-threaded section (-1: Same as inner diameter of the thread, 0: Same as outer diameter of the thread, value: The given value)
non_thread_diameter				= 0;	

/* [Nut Options] */

//Type: Normal or WingNut
nut_type	                    = "normal";//[normal,wingnut]
//Distance between flats for the hex nut
nut_diameter    				= 12;	
//Height of the nut
nut_height	  				    = 6;	
//Outer diameter of the bolt thread to match (usually set about 1mm larger than bolt diameter to allow easy fit - adjust to personal preferences) 
nut_thread_outer_diameter     	= 9;		
//Thread step or Pitch (2mm works well for most applications ref. ISO262: M3=0.5,M4=0.7,M5=0.8,M6=1,M8=1.25,M10=1.5)
nut_thread_step    				= 2;
//Step shape degrees (45 degrees is optimised for most printers ref. ISO262: 30 degrees)
nut_step_shape_degrees 			= 45;	
//Wing radius ratio.  The proportional radius of the wing on the wing nut compared to the nut height value (default = 1)
wing_ratio                      = 1;
wing_radius=wing_ratio * nut_height;

/* [Washer Options] */

//Inner Diameter (suggest making diameter slightly larger than bolt diameter)
inner_diameter					= 8;
//Outer Diameter
outer_diameter					= 14;
//Thickness
thickness					    = 2;

/* [Extended Options] */

//Number of facets for hex head type or nut. Default is 6 for standard hex head and nut
facets                          = 6;
//Number of facets for hole in socket head. Default is 6 for standard hex socket
socket_facets                   = 6;
//Depth of hole in socket head. Default is 3.5
socket_depth                    = 3.5;
//Resolution (lower values for higher resolution, but may slow rendering)
resolution    					= 0.5;	
nut_resolution    				= resolution;

module BuildFromType(type) {
//Hex Bolt

if (type=="bolt" && head_type=="hex")
{
	hex_screw(thread_outer_diameter,thread_step,step_shape_degrees,thread_length,resolution,countersink,head_diameter,head_height,non_thread_length,non_thread_diameter);
}

//Rod
if (type=="rod")
{
	hex_screw(thread_outer_diameter,thread_step,step_shape_degrees,thread_length,resolution,countersink,head_diameter,0,non_thread_length,non_thread_diameter);
}

//Hex Nut (normally slightly larger outer diameter to fit on bolt correctly)
if (type=="nut" && nut_type=="normal")
{
	hex_nut(nut_diameter,nut_height,nut_thread_step,nut_step_shape_degrees,nut_thread_outer_diameter,nut_resolution);
}

// We will make hex_nut and with covered end to form a cap!
if (type=="cap")
{
	hex_cap(nut_diameter,nut_height,nut_thread_step,nut_step_shape_degrees,nut_thread_outer_diameter,nut_resolution);
}

//Wing Nut variation of hex nut. Cylinders added to each side of nut for easy turning - ideal for quick release applications
if (type=="nut" && nut_type=="wingnut")
{
	rotate([0,0,30])hex_nut(nut_diameter,nut_height,nut_thread_step,nut_step_shape_degrees,nut_thread_outer_diameter,nut_resolution); //nut	
	translate([(nut_diameter/2)+wing_radius-1,1.5,wing_radius/2+1])rotate([90,0,0])wing(); //attach wing
	mirror(1,0,0)translate([(nut_diameter/2)+wing_radius-1,1.5,wing_radius/2+1])rotate([90,0,0])wing(); //attach wing
}
}

module wing()
{
	difference()
	{
		cylinder(r=wing_radius,h=3,$fn=64); //cylinder
		union()
		{
			translate([-wing_radius,-wing_radius-1,-0.5])cube([wing_radius*2,wing_radius/2,wing_radius*2]); //remove overhang so flush with base of nut		
			rotate([0,0,90])translate([-wing_radius,wing_radius-1,-0.5])cube([wing_radius*2,wing_radius/2,wing_radius*2]); //remove overhangs so flush with side of nut		
		}
	}
}

//Washer
if (type=="washer")
{
	difference()
	{
		cylinder(r=outer_diameter/2,h=thickness,$fn=100);
		translate([0,0,-0.1])cylinder(r=inner_diameter/2,h=thickness+0.2,$fn=100);
	}
}

//Socket Head Bolt
if (type=="bolt" && head_type!="hex")
{
	socket_screw(thread_outer_diameter,thread_step,step_shape_degrees,thread_length,resolution,countersink,head_diameter,head_height,non_thread_length,non_thread_diameter);
}

module phillips_base()
{
	linear_extrude(slot_width)polygon(points=[[0,0],[(drive_diameter-slot_width)/2,9/5*(drive_diameter-slot_width)/2],[(drive_diameter+slot_width)/2,9/5*(drive_diameter-slot_width)/2],[drive_diameter,0]]);
	translate([(drive_diameter-slot_width)/2,0,(drive_diameter+slot_width)/2])rotate([0,90,0])linear_extrude(slot_width)polygon(points=[[0,0],[(drive_diameter-slot_width)/2,9/5*(drive_diameter-slot_width)/2],[(drive_diameter+slot_width)/2,9/5*(drive_diameter-slot_width)/2],[drive_diameter,0]]);
}

module phillips_fillet()
{
	union()
	{
		translate([-(drive_diameter-slot_width)/2-(slot_width/2),slot_width/2,0])rotate([90,0,0])phillips_base();
		translate([0,0,9/5*(drive_diameter-slot_width)/2])union()
		{
			inner_curve();
			rotate([0,0,90])inner_curve();
			rotate([0,0,180])inner_curve();
			rotate([0,0,270])inner_curve();
		}
	}
}

module inner_curve()
{
	translate([slot_width/2,-slot_width/2,0])rotate([0,90,0])linear_fillet(9/5*(drive_diameter-slot_width)/2,drive_diameter/10);
}

//basic 2d profile used for fillet shape
module profile(radius)
{
  difference()
  {
    square(radius);
    circle(r=radius);
  }
}

//linear fillet for use along straight edges
module linear_fillet(length,profile_radius)
{
	translate([0,-profile_radius,profile_radius])rotate([0,90,0])linear_extrude(height=length,convexity=10)profile(profile_radius);
}

module phillips_drive()
{
	intersection()
	{
		phillips_fillet();
		cylinder(9/5*(drive_diameter-slot_width)/2,drive_diameter/2+(slot_width/2),slot_width/2);
	}
}

module socket_screw(od,st,lf0,lt,rs,cs,df,hg,ntl,ntd)
{
    ntr=od/2-(st/2)*cos(lf0)/sin(lf0);
	$fn=60;
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

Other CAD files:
models/PumpBoat.scad
models/PumpBoatOld.scad
models/WaterBlobPump.scad
models/ferofluid pump V1/ferofluid pump V1.f3d
models/ferofluid pump V1/ferofluid pump V1.stl
models/tray.scad

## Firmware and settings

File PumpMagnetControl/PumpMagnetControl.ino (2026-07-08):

const int NUM_MAGNETS = 2;

const int PIN_MAG_0 = 3;
const int PIN_MAG_1 = 4;
const int MAG_PINS[NUM_MAGNETS] = {3,4};
// 200 ms with magnets in series seems pretty good, with 0.4 time.
const unsigned int PERIOD_MS = 350;
const float timings[NUM_MAGNETS][2] = { {0.0, 0.4}, {0.0, 0.4} };


void setup() {
  // put your setup code here, to run once:
  Serial.begin(115200);
  pinMode(LED_BUILTIN, OUTPUT);
  pinMode(PIN_MAG_0,OUTPUT);
  pinMode(PIN_MAG_1,OUTPUT);
}

unsigned int time_within_period = 0;
long last_period_start = 0;
long period_number = 0;

int DEBUG_LEVEL = 1;
void loop() {
  // put your main code here, to run repeatedly:
  delay(5);
  unsigned long ms = millis();
  time_within_period = ms - last_period_start;
  Serial.print("time ");
  Serial.println(time_within_period);
  for(int i = 0; i < NUM_MAGNETS; i++) {
    bool MAG_ON = (time_within_period > (((float) PERIOD_MS) * timings[i][0]))
          && (time_within_period < ((float) PERIOD_MS)* timings[i][1]);
    if (DEBUG_LEVEL > 0) {
            Serial.print("mag: ");
            Serial.print(i);
            Serial.print(" ");
            Serial.print((time_within_period > (((float) PERIOD_MS) * timings[i][0])));
            Serial.print(" ");
            Serial.print((time_within_period < ((float) PERIOD_MS)* timings[i][1]));
            Serial.print(" ");
            Serial.println(MAG_ON);
    }
    digitalWrite(MAG_PINS[i],MAG_ON);
  }

  // now check if we are outside of a period
  if (time_within_period > PERIOD_MS) {
    Serial.print("Period: ");
    Serial.println(period_number++);
    digitalWrite(LED_BUILTIN, (period_number % 2));
    last_period_start = ms;
    time_within_period = 0;
  }
}

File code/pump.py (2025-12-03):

import machine
import time

stepPeriodMs = 2000
ioMap = [21, 19, 18, 5, 17, 16, 4]
pins = list(map(lambda io: machine.Pin(io, machine.Pin.OUT), ioMap))
statusLED = machine.Pin(2, machine.Pin.OUT)

# Pattern from https://github.com/PubInv/ferrofluid-pump/blob/main/doc/FerrofluidPump.pdf
cyclesPattern = [ [0, 0, 1, 0, 0, 1, 1],
                  [0, 1, 0, 0, 1, 1, 0],
                  [1, 0, 0, 1, 1, 0, 0],
                  [1, 0, 0, 1, 0, 0, 1] ]

while True:
    for i in range(len(cyclesPattern)):
        for j in range(len(cyclesPattern[i])):
            pins[j].value(cyclesPattern[i][j])
        print('Step ' + str(i + 1))
        statusLED.value(i % 2)

        time.sleep_ms(stepPeriodMs)

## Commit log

2022-05-05 initial Pump Frame
    [Body1.stl, WaterBlobPump.scad]
2022-05-31 adding up
    [Nut_Job_v2.scad, WaterBlobPump.scad]
2022-05-31 added locking rings
    [WaterBlobPump.scad]
2022-05-31 improving locks
    [WaterBlobPump.scad]
2023-02-18 adding stl file
    [WaterBlobPump.stl]
2024-01-16 ferofluid pump V1 test print -sid
    [ferofluid pump V1.f3d, ferofluid pump V1.step, ferofluid pump V1.stl]
2024-03-25 adding Joes physical design and Joses board design
2024-03-27 Check in the step without the zip
    [Pump.STEP]
2024-03-27 Make the wire holes 6mm instead of 4mm
    [Pump.STEP]
2024-04-03 adding Jose Olascoaga's pcb assembly design
2024-04-05 adding improved PCB
2024-07-12 Add test code for the prototype pump
    Add some documentation about how to setup the environment and run the code.
2025-12-03 add pump boat concept
    [PumpBoat.scad]
2026-01-27 Anson's edits to pump boat
    [PumpBoat.scad]
2026-02-19 updating pumpboag
    [PumpBoat.scad]
2026-03-05 new edits
    [PumpBoat.scad]
2026-03-06 minor changes to pump boat
    [PumpBoat.scad]
2026-03-12 new barbs
    [PumpBoat.scad]
2026-03-13 minor tweak
    [PumpBoat.scad]
2026-04-02 new changes
    [PumpBoat.scad]
2026-04-02 some tweaks
    [PumpBoat.scad]
2026-04-02 new chimney
    [PumpBoat.scad]
2026-04-04 making better
    [PumpBoat.scad]
2026-04-17 complete redesign of chimney
    [PumpBoat.scad]
2026-04-17 new design
    [PumpBoat.scad]
2026-05-02 Codex helped me make these improvements
    [PumpBoat-v2.scad]
2026-05-03 changing PumpBoat
    [PumpBoat-v2.scad]
2026-05-04 significant changes
    [PumpBoat-v2.scad, PumpBoatOld.scad, PumpWithTray.3mf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]
2026-07-02 adding version
    [PumpBoat.scad]
2026-07-02 adding the chamber
    [PumpBoat.scad]
2026-07-02 adding tray
    [tray.scad]
2026-07-02 updated version of chamber
    [PumpBoat.scad]
2026-07-03 final chamber
    [PumpBoat.scad]
2026-07-08 adding code for Robs setup
    [PumpBoat.scad]
2026-07-30 adding Anson's valve design
    [diodic valve.scad]
2026-08-02 update with major insights
    [PumpBoat.scad, diodic valve.scad]
2026-08-03 attempting to make improvements
    [PumpBoat.scad]
2026-08-20 addin Asmis funnelCup design, with mods from Rob
    [PumpBoat.scad, funnelCup.scad]
2026-09-01 attempted integration with funnel cup
    [PumpBoat.scad, funnelCup.scad]
2026-09-08 moving funnel into position, Asmi to complete
    [PumpBoat.scad]
2026-09-23 making an open design
    [PumpBoat.scad]
